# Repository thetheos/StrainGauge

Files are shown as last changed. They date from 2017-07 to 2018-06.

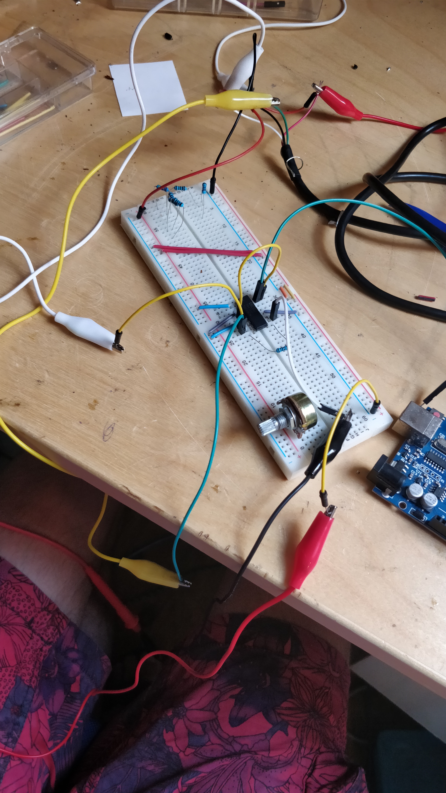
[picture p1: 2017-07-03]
photos/IMG_20170623_125851.jpg

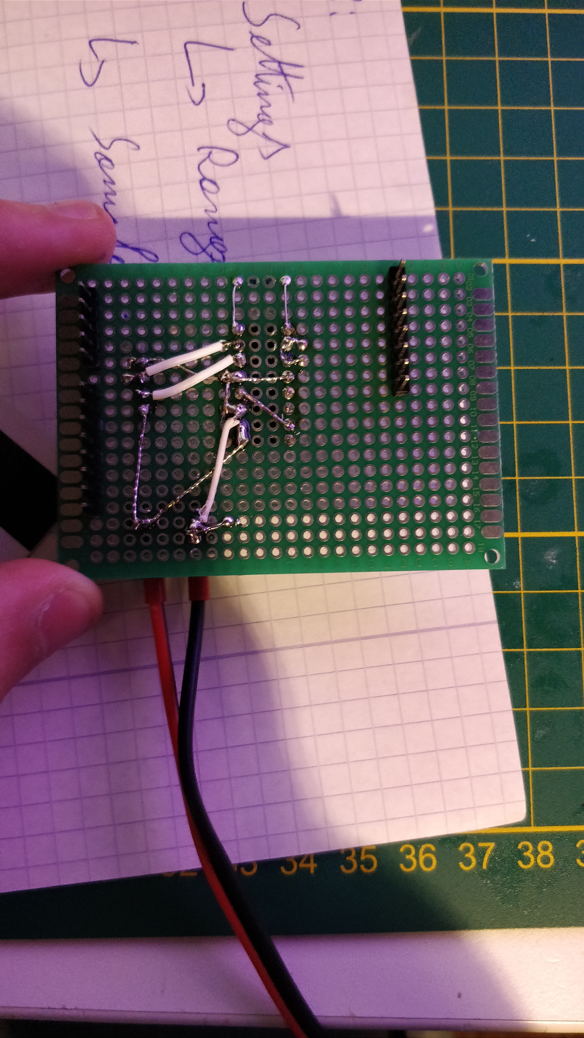
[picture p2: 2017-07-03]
photos/IMG_20170704_001055.jpg

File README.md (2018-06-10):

View this project on [CADLAB.io](https://cadlab.io/project/1158). 

# StrainGauge

Here is a proto shield for arduino uno to easily mount strain gauges. It uses the pin A1 to read the output of the instrumental
amp (ina125p).

I wrote also a small program wich can read the input of the signal on pin A1 and rewrite it on the serial monnitor (9600 baud). 
There is 2 mode of reading:
-Continuous reading (read in continuous...)
-Triger mode read: print data only when the strain gage is stressed. The triger mode settings can be modified in the program via serial
monitor (both the sensitivity of the triger and the sample rate).

This project was designed to measure the thrust power of a propellant motor.

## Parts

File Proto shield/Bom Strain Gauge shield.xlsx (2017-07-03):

pièce | quantité | prix | lien
S type strain gauge 100kg | 1 | 25.02 | https://www.aliexpress.com/item/strain-gauge-pressure-sensor-S-load-cell-electronic-scale-sensor-Weighing-Sensor-10KG-20KG-50KG-100KG/1083523348.html
Ina125p instrumentation amp | 5 | 14.44 | https://www.aliexpress.com/item/FREE-SHIPPING-INA125P-INA125-NA125P-125P-DIP-5PCS/32762598714.html
arduino uno | 1 | 3.52 | https://www.aliexpress.com/item/2014-The-new-Ard-uino-UNO-R3-Development-board-whit-cable-and-Row-needles-Experts-version/32372942893.html
trimpot 1Kohm | 45 | 4.86 | https://www.aliexpress.com/snapshot/0.html?orderId=84948777973876&productId=32383136652

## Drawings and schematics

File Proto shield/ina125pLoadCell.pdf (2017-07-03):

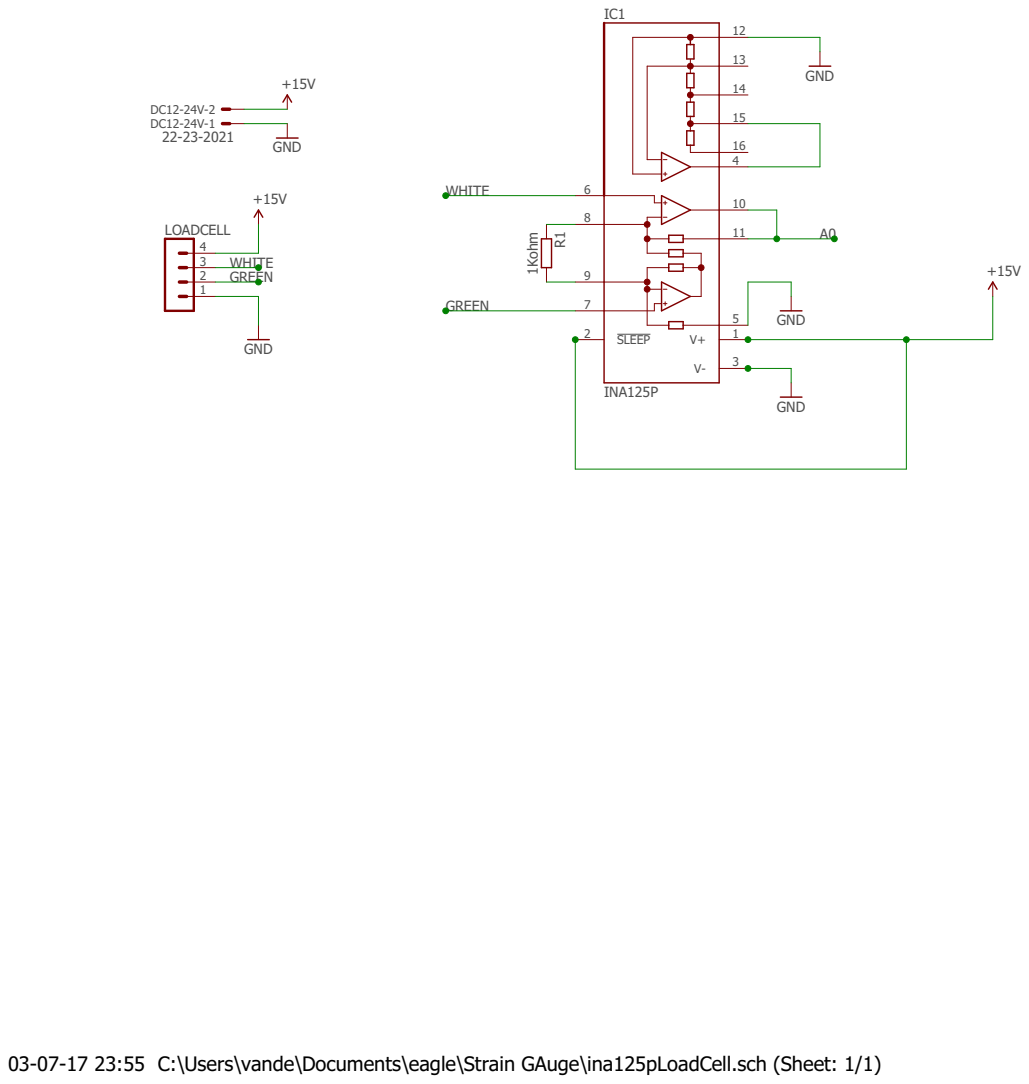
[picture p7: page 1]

03-07-17 23:55 C:\Users\vande\Documents\eagle\Strain GAuge\ina125pLoadCell.sch (Sheet: 1/1)

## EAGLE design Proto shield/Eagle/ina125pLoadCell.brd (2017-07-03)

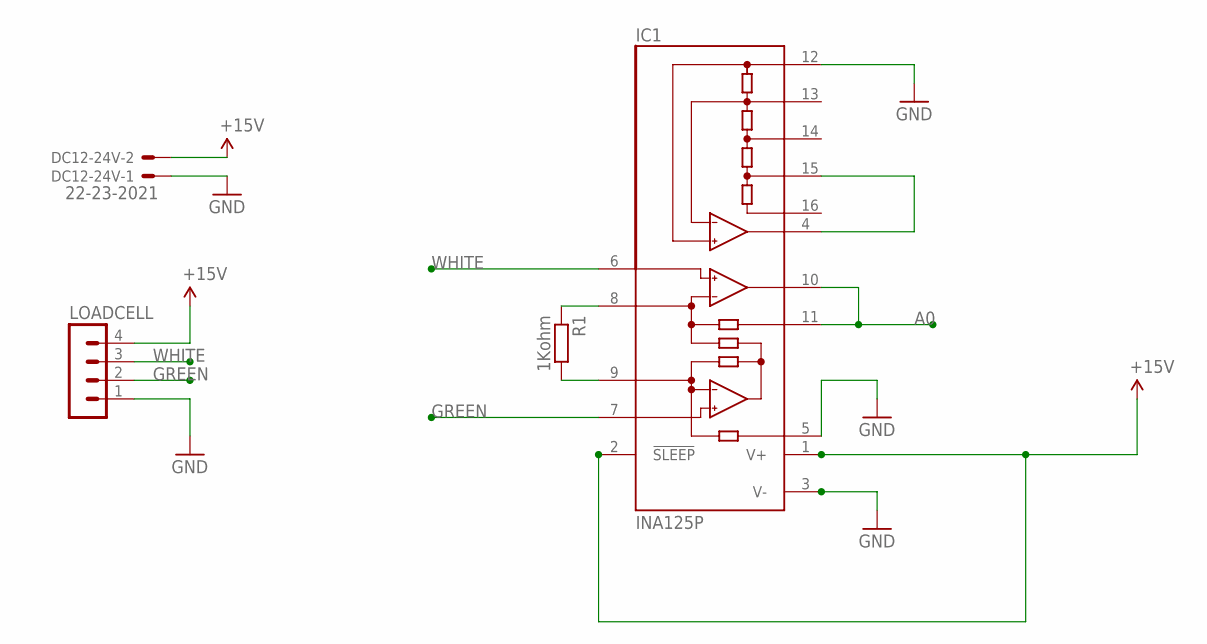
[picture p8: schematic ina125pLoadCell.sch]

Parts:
DC12-24V: 22-23-2021
IC1: INA125P; DIL16
LOADCELL: MA04-1
R1: 1Kohm; 0207/7

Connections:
+15V: IC1.1 (V+), IC1.2 (!SLEEP)
A0: IC1.10 (OUT), IC1.11 (SENSE)
AREF: IC1.4 (REFOUT), IC1.15 (REF5)
GND: DC12-24V.1, IC1.3 (V-), IC1.5 (REF), IC1.12 (REFCOM), LOADCELL.1
GREEN: IC1.7 (-IN), LOADCELL.2
unnamed: IC1.9 (RG), R1.2
unnamed: IC1.8 (RG), R1.1
VCC: DC12-24V.2, LOADCELL.4
WHITE: IC1.6 (+IN), LOADCELL.3

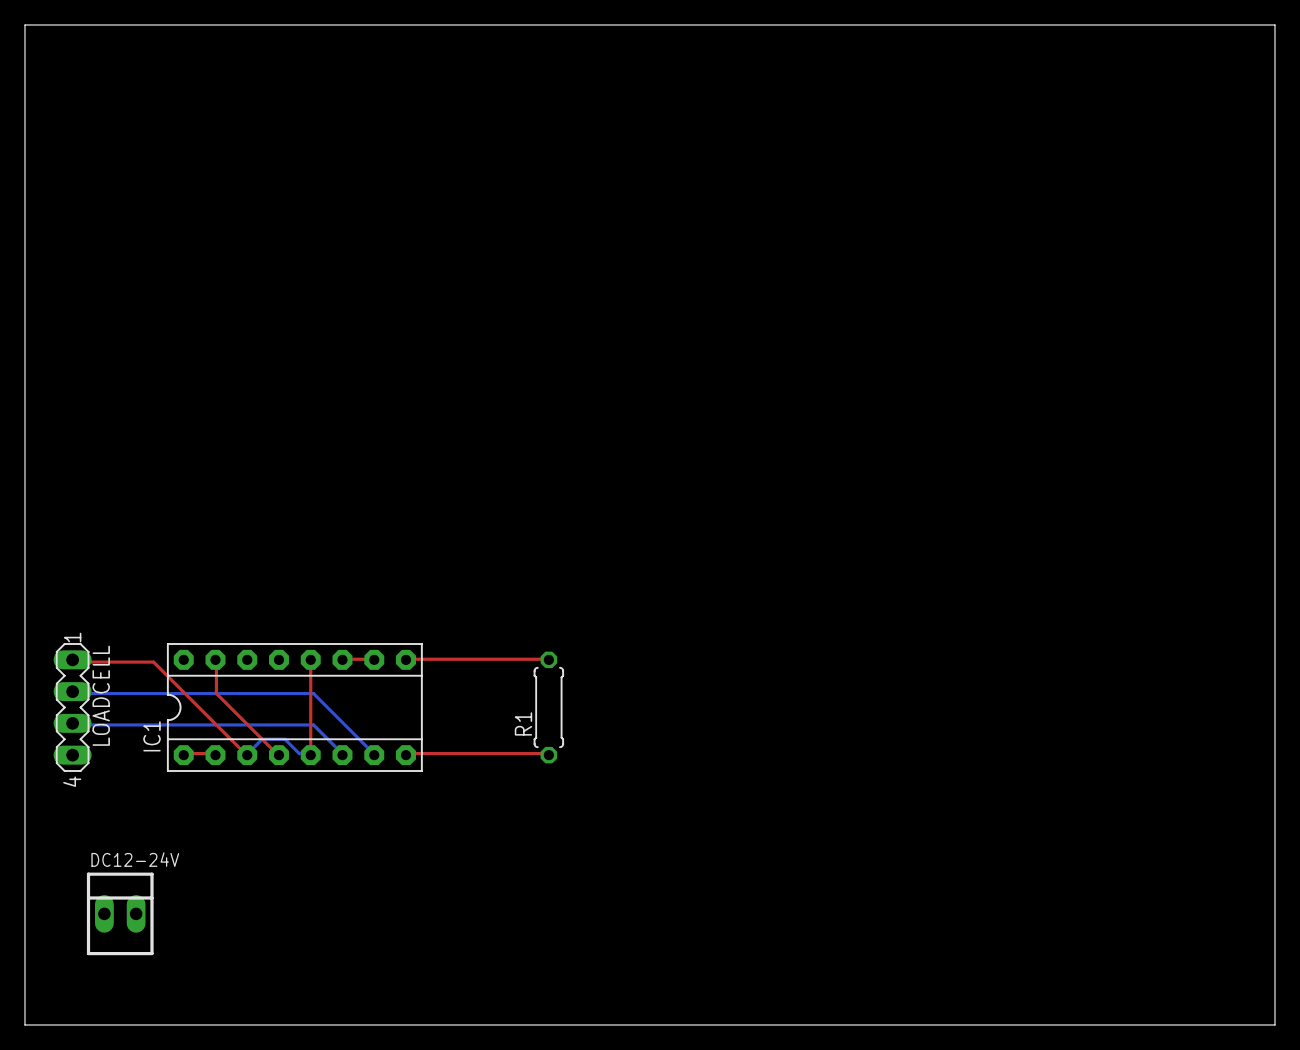
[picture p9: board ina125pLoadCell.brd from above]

Board: 2 copper layers, 100.0 x 80.0 mm, 4 parts (0 on the bottom side), 9 nets.

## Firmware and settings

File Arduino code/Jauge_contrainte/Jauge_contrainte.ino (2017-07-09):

int val;
int pin = 14;
int inputBuf=0;
int modeSelect = 1; //première couche
int range=5;
int sampleRate = 100;
String buff;
int temp;
int delayTime = 50;

String inputString = "";
volatile boolean stringComplete = false;

bool set0 = true;
bool set1 = true;
bool set2 = true;
bool set3 = true;

int modeSetup = 0; //deuxième couche
int settingSelect = 0;

void setup() {
  // put your setup code here, to run once:
  Serial.begin(9600);
  pinMode(pin, INPUT);
  Serial.println("Select your mode : continuous reading mode(1), triger mode(2), triger mode settings(3)");
  inputString.reserve(200);
  
}

void loop() {
  unsigned long startTime = millis();
  if(stringComplete == true && modeSetup == 0){
    temp = inputString.toInt();
    modeSelect = temp;
    inputString = "";
    stringComplete = false;
  }

  if(modeSelect==0){
  }
  else if(modeSelect==1){
    val = analogRead(pin);
    Serial.print(startTime);
    Serial.print('\t');
    Serial.println(val);
    delay(delayTime);
  }
  else if(modeSelect==2){
    triger();
  }
  else if(modeSelect == 3){
    trigerSetup();
    
  }
  else {
    Serial.println("incorect input");
    delay(500);
  }
}

void triger(){
  unsigned long startTime = millis();
  int val1 = analogRead(pin);
  delay(20);
  int val2 = analogRead(pin);
  int valf = val2-val1;

  
  if(valf>range || valf<-range){
    for(int i = 0; i<sampleRate; i++){
      int val = analogRead(pin);
      Serial.print(startTime);
      Serial.print('\t');
      Serial.println(val);
    }
  }
  else if(valf<range || valf>-range){
  
  }
  
}

void trigerSetup(){
  if(set0 && modeSetup == 0){
    Serial.println("Triger setup mode: range setup(1), sample rate setup(2),delay setup(3), quit(4)");
    set0 = false;
    modeSetup = 1;
  }
  
  if(stringComplete == true && modeSetup == 1){
    temp = inputString.toInt();
    settingSelect = temp;
    inputString = "";
    stringComplete = false;
  }
  if(settingSelect == 0){}
  else if(settingSelect == 1)
    trigerSetupRange();
  else if(settingSelect == 2)
    trigerSetupSampleRate();
  else if(settingSelect == 3)
    delayTimeSetup();
  else if(settingSelect == 4){
    modeSetup = 0;
    Serial.println("Select your mode : continuous reading mode(1), triger mode(2), triger mode settings(3)");
    settingSelect = 0;
    modeSelect = 0;
    set0 = true;
  }   
  else
    Serial.println("incorrect input");
}

void trigerSetupRange(){
   if(set1){
    Serial.print("Actual range: ");
    Serial.println(range);
    Serial.println("Set new range: "); 
    set1 = false;
    modeSetup = 2;
   }
   if(stringComplete == true && modeSetup == 2){
    temp = inputString.toInt();
    range = temp;
    Serial.print("new range: ");
    Serial.println(range);
    inputString = "";
    stringComplete = false;
    modeSetup =1;
    set0 = true;
   }
}

void trigerSetupSampleRate(){
   if(set2){
    Serial.print("Actual SampleRate: ");
    Serial.println(sampleRate);
    Serial.println("Set new sampleRate: "); 
     Serial.println("Triger setup mode: range setup(1), sample rate setup(2),delay setup(3), quit(4)");
    set2 = false;
    modeSetup = 2;
   }
   if(stringComplete == true && modeSetup == 2){
    temp = inputString.toInt();
    sampleRate = temp;
    Serial.print("new sampleRate: ");
    Serial.println(sampleRate);
     Serial.println("Triger setup mode: range setup(1), sample rate setup(2),delay setup(3), quit(4)");
    inputString = "";
    stringComplete = false;
    modeSetup =1;
    set0 = true;
   }
}

void delayTimeSetup(){
   if(set3){
    Serial.print("Actual delay: ");
    Serial.println(delayTime);
    Serial.println("Set new delay: "); 
    set3 = false;
    modeSetup = 3;
   }
   if(stringComplete == true && modeSetup == 3){
    temp = inputString.toInt();
    delayTime = temp;
    Serial.print("new delay: ");
    Serial.println(delayTime);
     Serial.println("Triger setup mode: range setup(1), sample rate setup(2),delay setup(3), quit(4)");
    inputString = "";
    stringComplete = false;
    modeSetup =1;
    set0 = true;
   }
}

void serialEvent(){
  while (Serial.available()) {
    // récupérer le prochain octet (byte ou char) et l'enlever
    char inChar = (char)Serial.read(); 
    // concaténation des octets reçus
    inputString += inChar;
    // caractère de fin pour notre chaine
    if (inChar == '\n') {  
      stringComplete = true;
    }
  }
}

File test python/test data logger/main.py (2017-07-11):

#-*- coding: utf-8 -*-

import serial

import matplotlib.pyplot as plt
import numpy as np
from drawnow import *

plt.ion()

buff = 0
inputVal = ['0','0'] #obliger d'initialiser le tableau
inputValInt = []
inputValInt1= []

arduino = serial.Serial('COM4', 9600, timeout=1)
fichier = open('data.txt', 'wb')

def plotValues():
	plt.plot(inputValInt, inputValInt1, 'o-')
	plt.grid(True)
	plt.ylim(300,500)

	plt.show()
	


while 1:
	while arduino.inWaiting():
		buff = arduino.readline()
		print(buff.decode('utf-8'))
		#print(buff.split())
		inputVal = buff.split()
		inputValUtf = [inputVal[0].decode('utf-8'),inputVal[1].decode('utf-8')]
		#print(inputValUtf[0])
		#print(inputValUtf[1])

		try:
			inputValInt.append(int(inputValUtf[0]))
			inputValInt1.append(int(inputValUtf[1]))
			#print(inputValInt1)
		except:
			print("")

		drawnow(plotValues)
		fichier.write(buff)


	

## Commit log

2017-07-06 add time and delay setting plus bug correction/
    [Jauge_contrainte.ino]
2017-07-21 Add logger, reset button, solve multiple bug, enlarge TODO list
    [test.py]

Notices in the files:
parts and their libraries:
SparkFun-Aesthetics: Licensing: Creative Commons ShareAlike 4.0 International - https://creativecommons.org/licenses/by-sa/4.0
